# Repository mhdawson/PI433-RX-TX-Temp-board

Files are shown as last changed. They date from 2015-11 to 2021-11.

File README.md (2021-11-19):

# Circuit board for Home alarm and temperature monitoring

This projects contains information and schematics for a board that
can be used with the Raspberry PI in order to provide the hardware for these
projects:

+ https://github.com/mhdawson/PI433WirelessRecvManager
+ https://github.com/mhdawson/PI433WirelessTXManager
+ https://github.com/mhdawson/PILocalTemp
+ https://github.com/mhdawson/HomeAlarm 
+ https://github.com/mhdawson/HouseDashboard

It combines the hardware needed for those projects onto a single
PCB with all the required components.

The project provides the kicad files (free from http://kicad.org) with the
board design that can be used to create the set of files needed
by a PCB manufacturer.

I validated the board by having batch built by www.pcbway.com, building one
and trying it out.  It seem to work but as always use at your own risk

It was my first board and I did not work to hard on it so there are a
few ways that it could be improved:

+ better silk screen layout - some of the screen identifying the parts is cut off

+ the solder holes for the antenas turned out to be under the RX module which
  is not what I had intended.

# Part List 

+ 1N4148 diode
+ 1K resistor
+ 4.7k resitor
+ BX-TM01-433 Transmitter module
+ RXB6 - receiver module
+ DS18B20 1-wire temperator sensor
+ 2 by 20pin header
+ 2 17cm wires for the antenas

See the references projects for more details 

# Key Files

+ 433-v1.kicad_pcb
+ 433-v1.net
+ 433-v1.pro
+ 433-v1.sch
+ 433-v1.dsn
+ 433-v1-cache.lib
+ 433-v1.xml

# Building gerber files needed to send to PCB manufacturer

+ check out the project
+ install kicad and open the v433-v1.pro project file
+ follow the instructions here: https://www.wayneandlayne.com/blog/2013/02/27/kicad-tutorial-gerber-file-generation/

# Pictures

## Kicad board layout
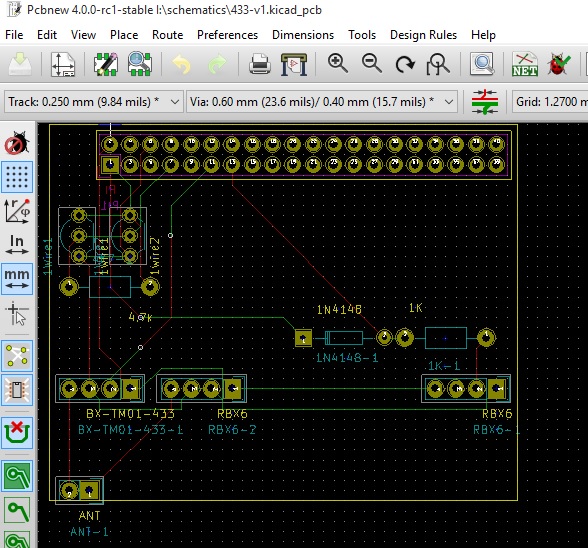
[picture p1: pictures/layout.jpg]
kicad board layout


## Kicad wiring diagram 
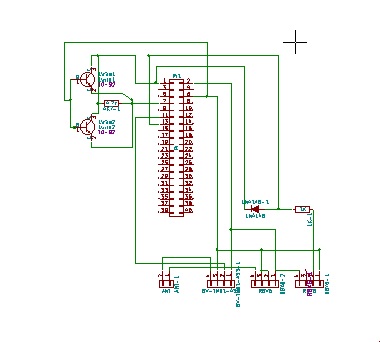
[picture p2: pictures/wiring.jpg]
kicad wiring diagram


## Front and back of board
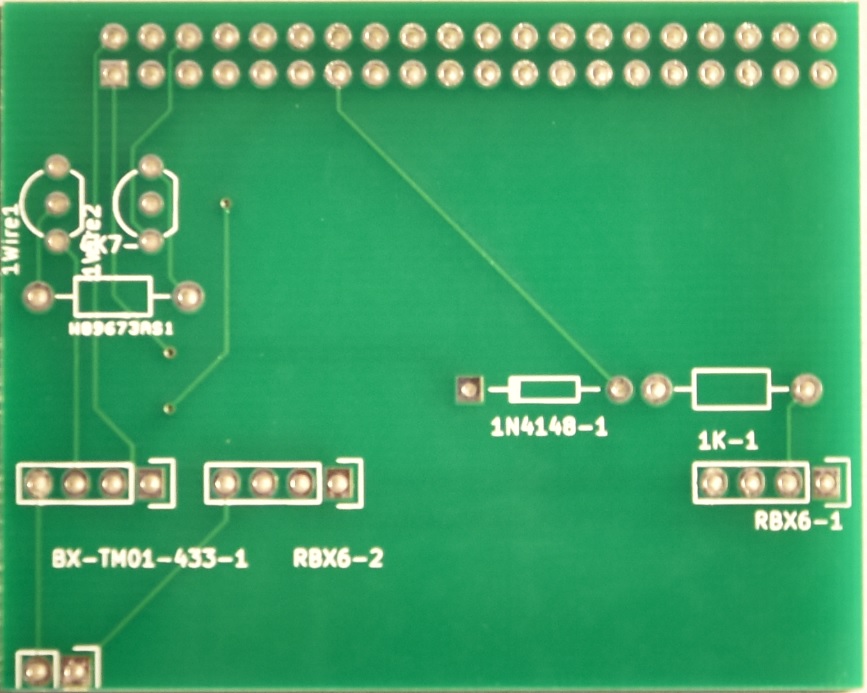
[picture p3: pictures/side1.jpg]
board side 1


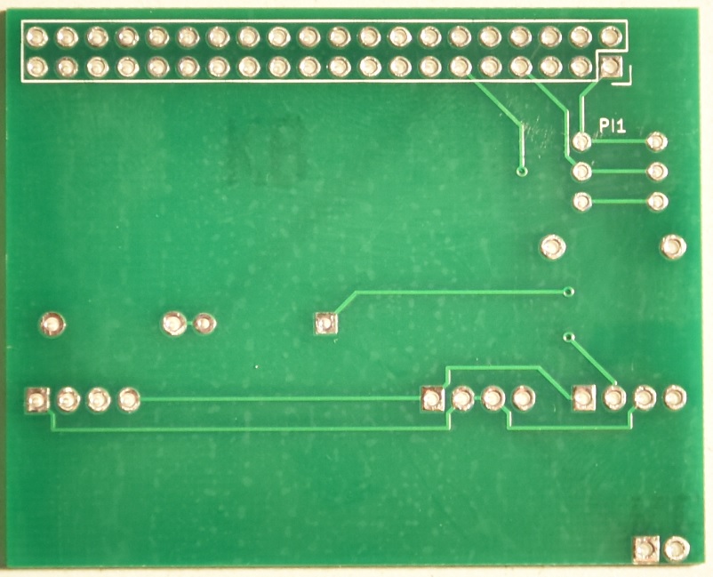
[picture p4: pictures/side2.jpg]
board side 2


## Front and back of populated board
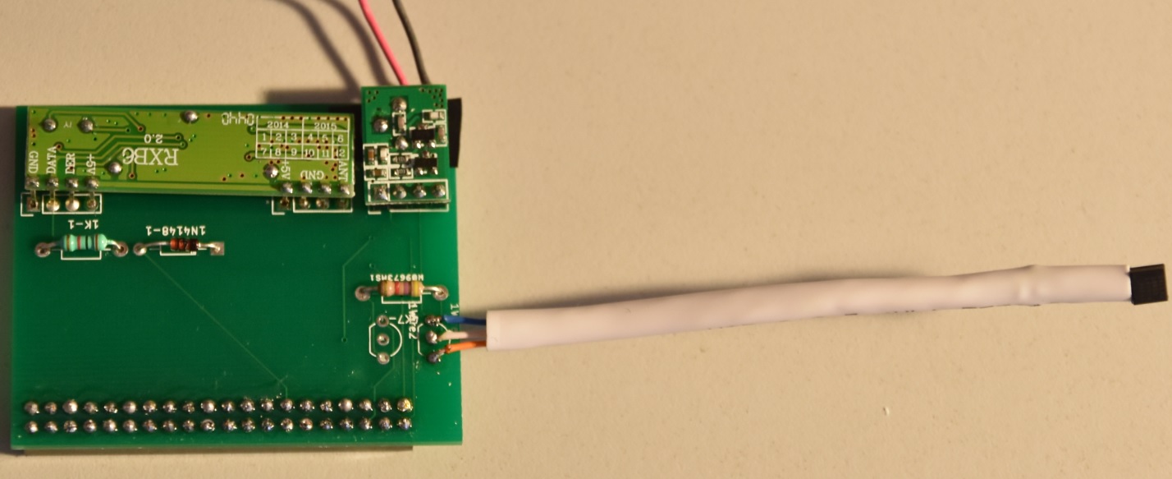
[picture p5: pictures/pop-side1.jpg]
board populated side 1


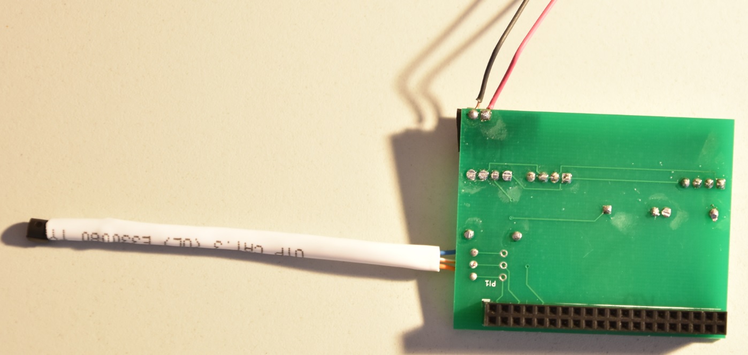
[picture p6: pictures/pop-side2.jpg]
board populated side 2


## Board mounted in Pi
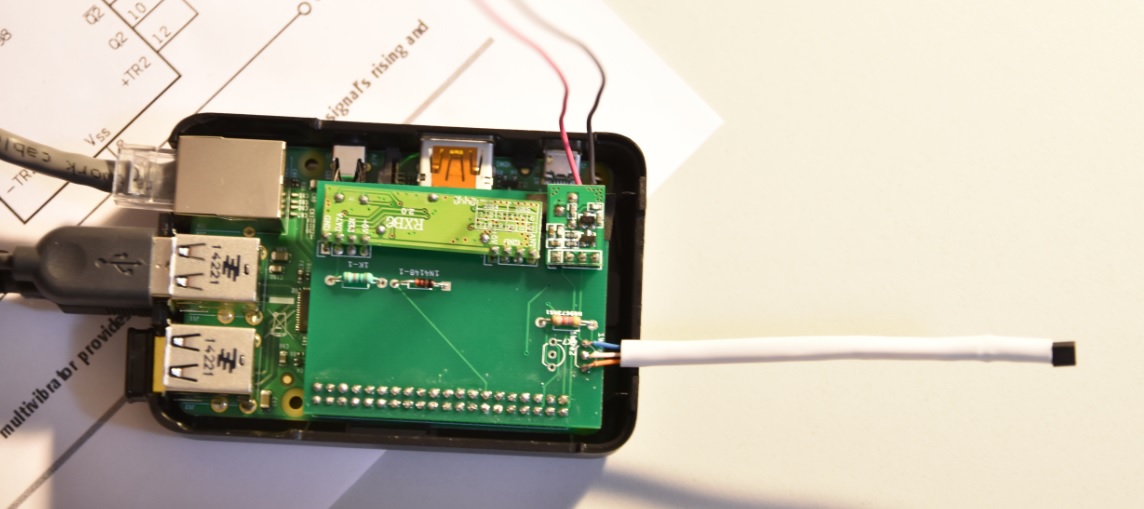
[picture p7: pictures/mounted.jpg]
Mounted in Pi


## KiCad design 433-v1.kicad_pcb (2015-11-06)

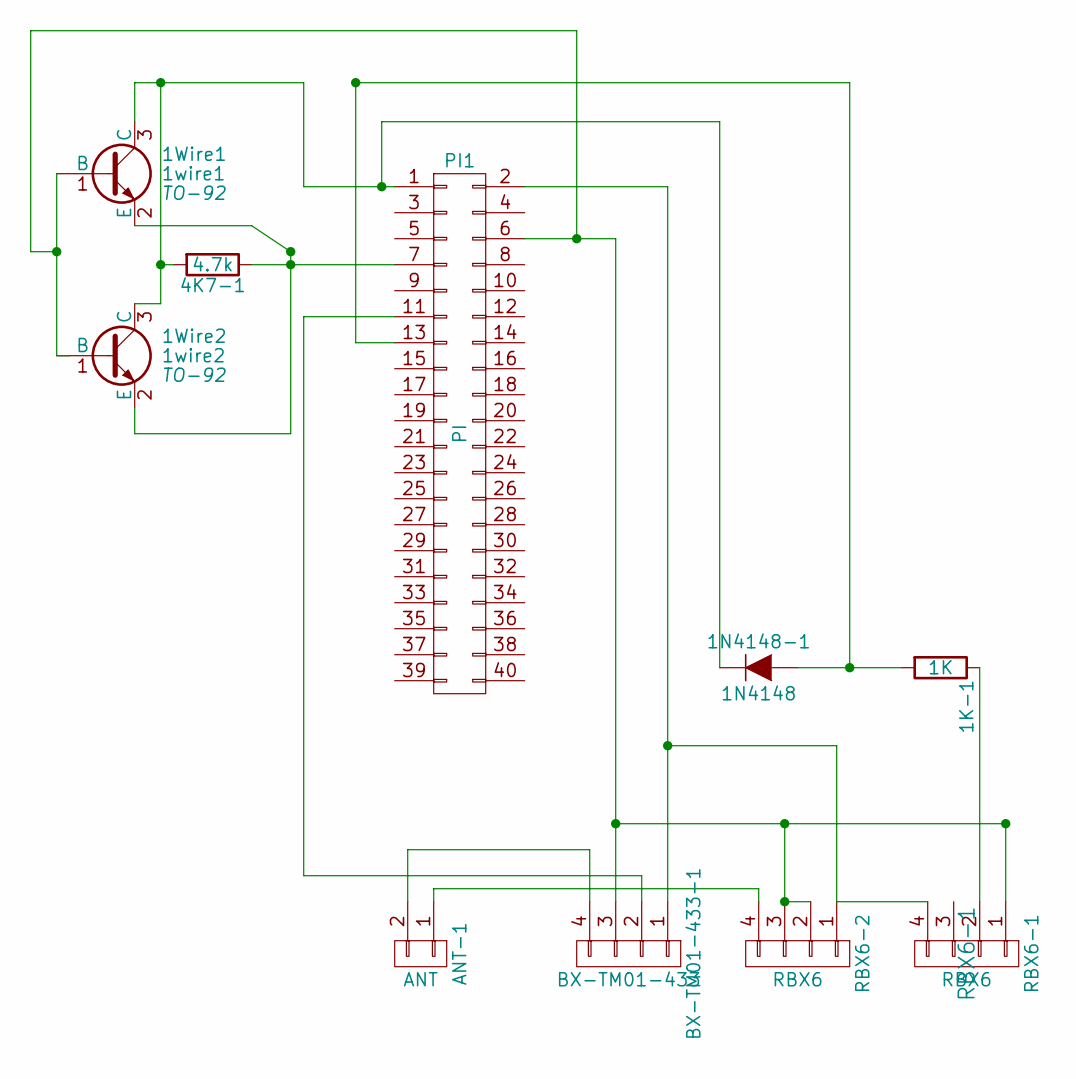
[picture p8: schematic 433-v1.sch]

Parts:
1K-1: 1K
1N4148-1: 1N4148
1Wire1: 1wire1; TO-92
1Wire2: 1wire2; TO-92
4K7-1: 4.7k
ANT-1: ANT
BX-TM01-433-1: BX-TM01-433
PI1: PI
RBX6-1: RBX6; RBX6-1
RBX6-2: RBX6

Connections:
unnamed: 1K-1.1, RBX6-1.2
unnamed: 1K-1.2, 1N4148-1.2 (A), PI1.13
unnamed: 1N4148-1.1 (K), 1Wire1.3 (C), 1Wire2.3 (C), 4K7-1.2, PI1.1
unnamed: 1Wire1.1 (B), 1Wire2.1 (B), BX-TM01-433-1.3, PI1.6, RBX6-1.1, RBX6-2.2, RBX6-2.3
unnamed: 1Wire1.2 (E), 1Wire2.2 (E), 4K7-1.1, PI1.7
unnamed: ANT-1.1, RBX6-2.4
unnamed: ANT-1.2, BX-TM01-433-1.4
unnamed: BX-TM01-433-1.1, PI1.2, RBX6-1.4, RBX6-2.1
unnamed: BX-TM01-433-1.2, PI1.11

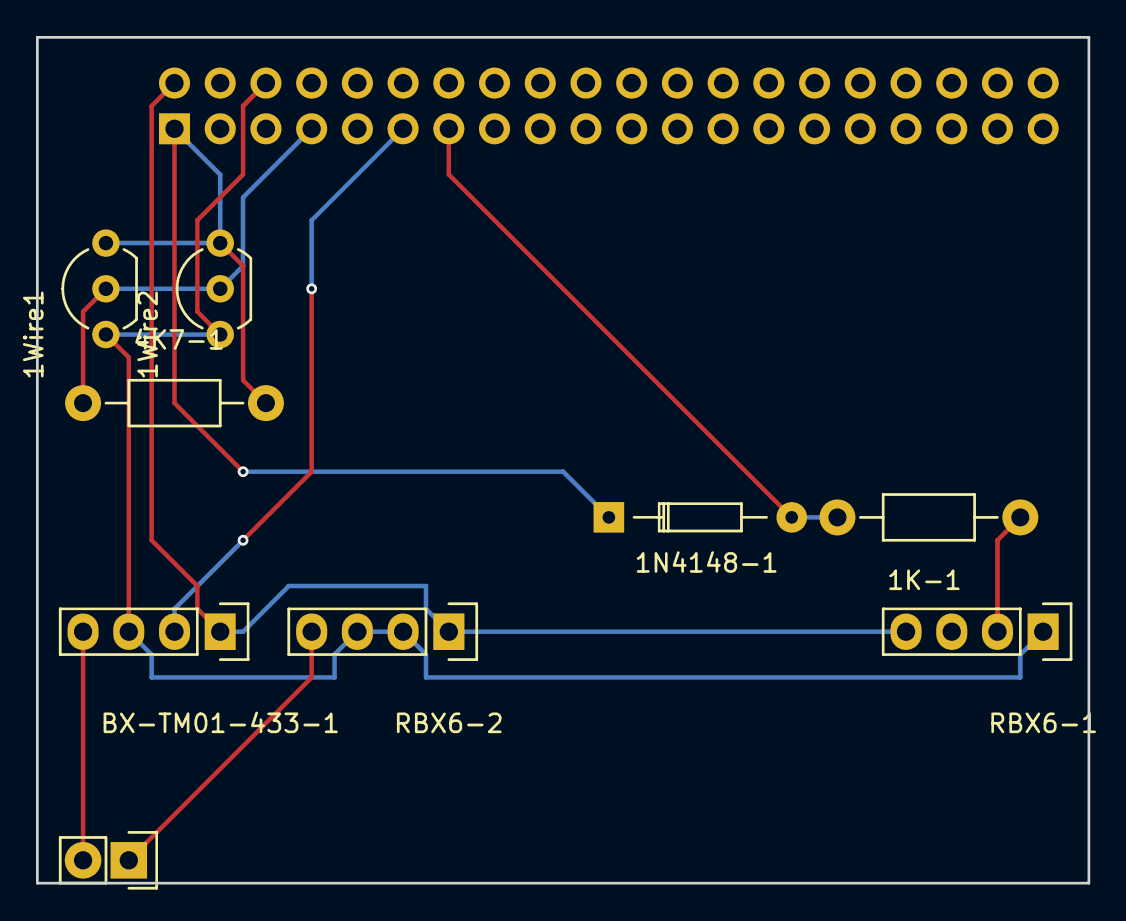
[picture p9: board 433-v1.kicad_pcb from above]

Board: 2 copper layers, 58.4 x 47.0 mm, 10 parts (1 on the bottom side), 9 nets.

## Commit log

2015-11-06 Initial version of files
    [433-v1.dsn, 433-v1.kicad_pcb, 433-v1.sch]
2015-11-06 Add info on creating gerber files
2021-11-10 Update README.md
    https://forum.kicad.info/t/warning-avoid-all-links-to-kicad-pcb-org-use-kicad-org/31521
